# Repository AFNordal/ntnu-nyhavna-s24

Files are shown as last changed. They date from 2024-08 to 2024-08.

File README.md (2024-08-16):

 # My work at NTNU, summer '24
 ## Tracker box
Each tracker box contains a Marble Pico (RP2040 based development board), a BMI270 IMU and two F9P-ZED RTK compatible GNSS receivers with antennas. Everything is powered by a simple USB power bank. 

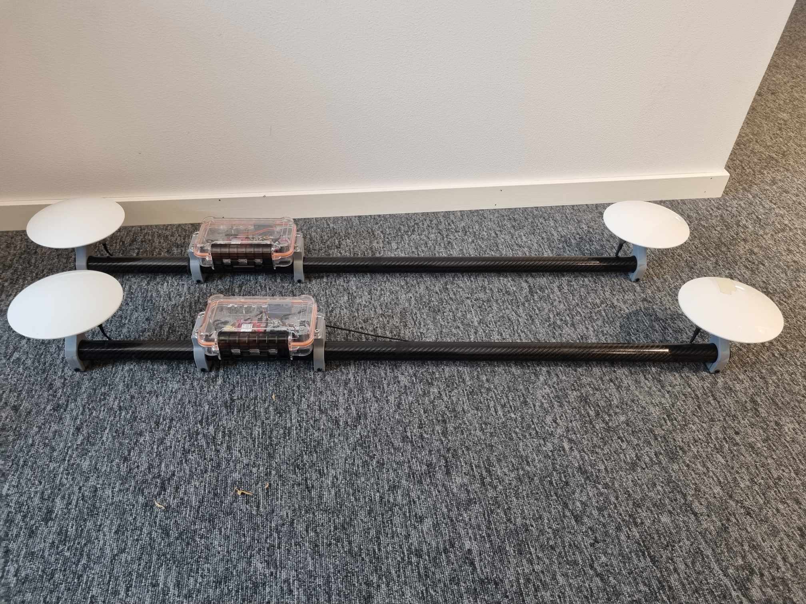
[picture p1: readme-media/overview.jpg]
Overview of tracker box assemblies


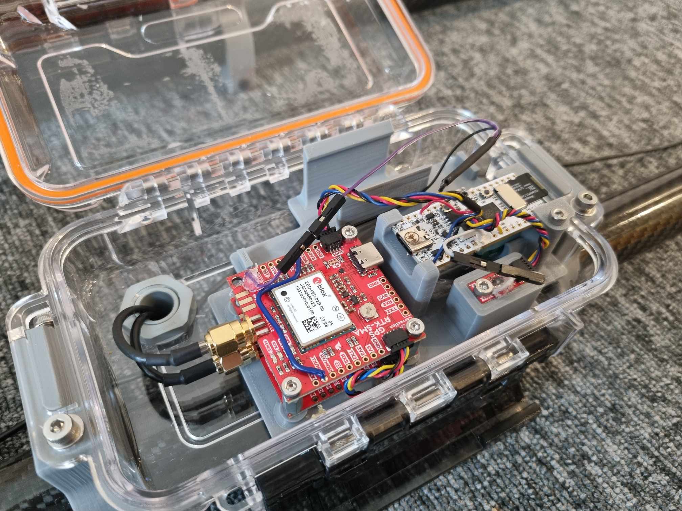
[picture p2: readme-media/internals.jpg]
Internals of tracker box


The boxes' purpose is to log accurately timed position and orientation data of maritime vessels.

 ### Usage
 1. Make sure the SD card is properly formatted, has enough free storage, and is inserted in the Pico. The card does not need to be emptied, and old files are not overwritten.
 2. Make sure that the three jumper cables and all I2C bus connectors are connected.
 3. Connect USB power to the Pico. After four seconds, the built-in LED on the pico should start blinking with two short blinks per second. If anything else happens, see [Troubleshooting](#Troubleshooting).
 4. Close the box and go track something.
 5. When you're done, simply unplug power. The onboard capacitor gives the Pico time to flush and close all files.
 6. The SD card now contains these files:
    - `IMU-[n].bin`
      - Contains raw IMU data in binary.
    - `F9P0-[n].bin` and `F9P1-[n].bin`
      - Contains raw F9P messages in binary.
    - `.count`
      - Contains the number `n` used in the file names of the newest data files. This is automatically incremented or created.

 #### Troubleshooting
When everything is working normally, the built-in LED on the Pico should blink with two short blinks each second.

If there is only one short blink each second, then core 1 of the Pico has become unresponsive. This has not occurred with the latest firmware version. Try resetting, power cycling, or re-flashing.

If the LED blinks quickly with 50% duty cycle, there has been a fatal error. Currently, this can be caused by:

 - Fatal error during SD card file system initialization
 - Unsuccessful IMU initialization
 - Fatal internal IMU error after initialization

Make sure that the SD card is properly inserted and that the I2C bus of the IMU is properly connected to the Pico, then reset or power cycle the Pico.

If the LED blinks quickly with ~16% duty cycle, the Pico has detected a brown-out and has flushed and closed all SD card writers to avoid corrupting the file system. A false detection has not yet occured. Resetting the Pico should restart the logging.

 ### Parsing

 #### Data format
The F9P data streams are copied directly to the data files.

The IMU data is stored as a stream of raw, little-endian structs. The struct is defined as
```
typedef struct
{
    bmi_data_t data;
    uint32_t sample_idx;
    uint8_t stamped;
    uint32_t _dummy0[3]; // To make the struct 32 bytes long
} IMU_sample_t;
```
where `bmi_data_t` is defined as
```
typedef struct
{
    int16_t ax;
    int16_t ay;
    int16_t az;
    int16_t gx;
    int16_t gy;
    int16_t gz;
} bmi_data_t;
```
This means that the data is structured as follows:

| byte # | field | type |
| ----- | --- | ---- |
| 0-1 | acc_x | int16 |
| 2-3 | acc_y | int16 |
| 4-5 | acc_z | int16 |
| 6-7 | acc_x | int16 |
| 8-9 | acc_y | int16 |
| 10-11 | acc_z | int16 |
| 12-15 | sample index | uint32 |
| 16 | acc_z | bool (uint8) |
| 17-31 | dummy | n.a. |

In python, this can be decoded with
```
struct.unpack("<" + "h"*6 + "I" + "B"*4 + "I"*3, raw_bytes)
```
which is applied in the next subsection.

 #### Parsing framework
The `parsing` directory contains a framework for parsing raw tracking data, synchronizing IMU data and F9P timestamps, plus some simple visualization tools. You can for instance replay the IMU data like seen below.

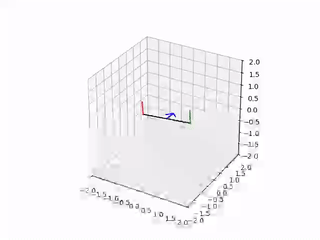
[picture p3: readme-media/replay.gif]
Animation of replayed IMU orientation


 ### Schematic
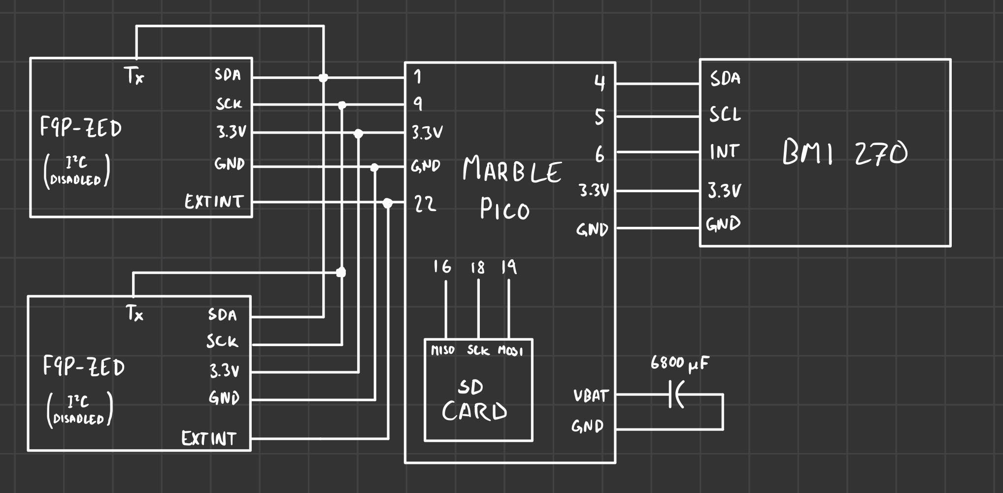
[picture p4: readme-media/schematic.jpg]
Schematic of Pico, F9Ps and IMU


 ### Firmware
The firmware uses both cores, `I2C0`, `UART0`, `UART1`, one alarm pool, four DMA channels and `DMA_IRQ_1`. The [SD card library](https://github.com/carlk3/no-OS-FatFS-SD-SDIO-SPI-RPi-Pico) uses two more DMA channels, `SPI0` and `DMA_IRQ_0`.

Core 0 handles initialization of the F9P interface, SD file system, and voltage monitoring. It is responsible for LED control, all SD operations, and voltage monitoring.

Core 1 handles initialization of the IMU and IMU interface, and is responsible for reading IMU data.

For accurate timestamping, the IMU data ready (DRDY) pulse is periodically forwarded to the F9Ps' EXTINT. This should happen around once every 2s. To be able to align IMU data and F9P timestamps that are offset by more than 2s, the interval between each pulse-forward is decreased by one IMU DRDY pulse for each pulse-forward. Every 64 pulse-forwards the interval is reset.

When a pulse is forwarded, the corresponding IMU sample's `stamped` field is set to 1. For all other samples it is set to 0.

The following two diagrams provide an overview of interactions with the IMU and F9Ps, respectively.

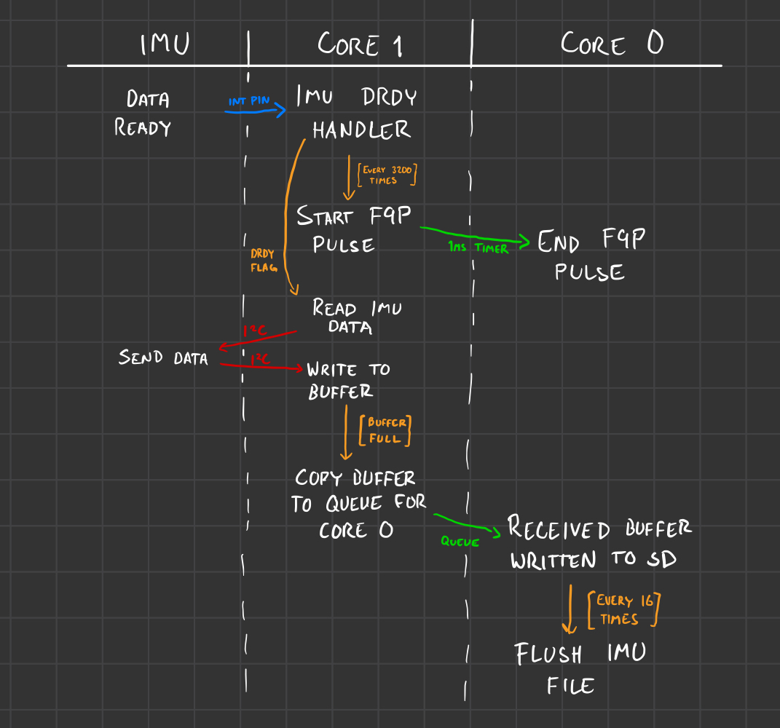
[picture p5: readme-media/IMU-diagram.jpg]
IMU diagram

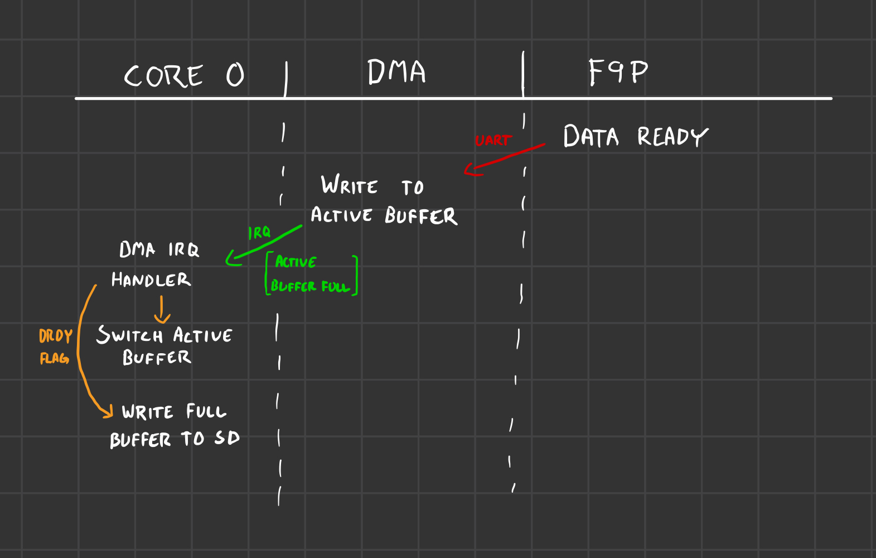
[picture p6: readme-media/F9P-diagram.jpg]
F9P diagram


 ## CAD work
I have also done some work in CAD to design the mounts and brackets for the tracking boxes, as well as some mounts for a different sensor rig. The `.f3z` archive files for all of these are also in this repository.

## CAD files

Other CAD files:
other cad/kamera-lidar-gnss v10.f3z
other cad/motor-bracket v7.f3d
tracking-box/CAD/ror-feste v8.f3d
tracking-box/CAD/tracker-box-2 v11.f3d

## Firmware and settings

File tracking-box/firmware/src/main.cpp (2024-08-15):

#include <stdio.h>

#include "pico/stdlib.h"
#include "pico/multicore.h"
#include "pico/util/queue.h"
#include "sys_utils.h"
#include "bmi270.h"
#include "sd_utils.h"
#include "battery.h"
#include "f9p.h"

// No. of 32 bytes long structs to be buffered before writing to sd
#define IMU_BUF_SIZE 1536
#define F9P_INTERRUPT_INTERVAL_S 2
#define F9P_INTERRUPT_PIN 22
#define F9P_RX0_PIN 1
#define F9P_RX1_PIN 9
#define BMI_DRDY_PIN 6
#define BMI_SDA_PIN 4
#define BMI_SCL_PIN 5

// Used to communicate to core 0 that core 1 is alive
queue_t heartbeat_queue;

// Whether main power is disconnected
volatile bool pwr_disconnected = false;
// Whether IMU has new data
volatile bool IMU_drdy = false;
// Whether the IMU is ready to take real readings
volatile bool IMU_armed = false;
// Whether the most recent IMU sample coincides with a pulse to the F9P's
volatile bool IMU_sample_stamped = false;
volatile uint32_t IMU_sample_idx = 0;
queue_t IMU_queue;

typedef struct
{
    bmi_data_t data;
    uint32_t sample_idx;
    uint8_t stamped;
    uint32_t _dummy0[3]; // To make the struct 32 bytes long
} IMU_sample_t;

void core1_entry(void);

// callback for when IMU has new data ready
void IMU_drdy_handler(uint gpio, uint32_t event_mask)
{
    static uint8_t stamp_offset = 32;
    static uint32_t prev_stamped = 0;
    if (IMU_armed && (IMU_sample_idx - prev_stamped == stamp_offset + BMI_ODR_HZ * F9P_INTERRUPT_INTERVAL_S))
    {
        prev_stamped = IMU_sample_idx;
        IMU_sample_stamped = true;
        f9p_send_interrupt();
        if (stamp_offset-- == 0)
            stamp_offset = 64;
    }
    else
    {
        IMU_sample_stamped = false;
    }
    IMU_drdy = true;
}

// Checks vbus voltage
void adc_handler(uint16_t level)
{
    if (level < 1600)
        pwr_disconnected = true;
}

int main()
{
    stdio_init_all();
    set_sys_clock_133mhz();
    led_init();
    busy_wait_cycles_ms(4000);

    queue_init(&heartbeat_queue, sizeof(uint8_t), 1);

    FATFS fs;
    sd_mount(&fs);

    // Read 'count' from .count file; Increment count and use
    // result in file names to avoid overwriting.
    FIL count_file;
    sd_open(&count_file, ".count", FA_WRITE | FA_READ | FA_OPEN_ALWAYS);
    char count_buf[32];
    uint32_t count;
    if (sd_readnum(&count_file, &count) != PICO_OK)
        count = 0;
    else
        count++;
    sd_rewind(&count_file);
    sd_writenum(&count_file, count);
    sd_close(&count_file);

    // Create IMU file
    FIL IMUfile;
    char filename[32];
    sprintf(filename, "IMU-%d.bin", count);
    sd_open(&IMUfile, filename, FA_CREATE_ALWAYS | FA_WRITE);

    // Create F9P files
    FIL F9Pfile0, F9Pfile1;
    char filename0[32], filename1[32];
    sprintf(filename0, "F9P0-%d.bin", count);
    sprintf(filename1, "F9P1-%d.bin", count);
    sd_open(&F9Pfile0, filename0, FA_CREATE_ALWAYS | FA_WRITE);
    sd_open(&F9Pfile1, filename1, FA_CREATE_ALWAYS | FA_WRITE);

    INFO("SD file system initialized\n");

    alarm_pool_t *core0_alarms = alarm_pool_get_default();
    // Poll capacitor voltage every 5ms
    battery_init(5, adc_handler, core0_alarms);
    INFO("Battery management initialized\n");

    // Timer used to pulse interrupt pin
    f9p_init(F9P_RX0_PIN, F9P_RX1_PIN, F9P_INTERRUPT_PIN, core0_alarms);
    INFO("F9P's initialized\n");

    queue_init(&IMU_queue, sizeof(IMU_sample_t) * IMU_BUF_SIZE, 1);
    multicore_launch_core1(core1_entry);
    INFO("Launched core 1\n");

    uint16_t write_count = 0;
    IMU_sample_t *IMUbuffer = new IMU_sample_t[IMU_BUF_SIZE];
    uint8_t *F9Pbuffer = new uint8_t[F9P_BUF_SIZE];
    while (!pwr_disconnected)
    {
        heartbeat_blink(&heartbeat_queue);

        uint32_t datarate;
        if (f9p_chan0_drdy(&F9Pbuffer))
        {
            sd_write(&F9Pfile0, F9Pbuffer, F9P_BUF_SIZE);
            sd_sync(&F9Pfile0);
            INFO("Wrote F9P0 file\n");
        }
        if (f9p_chan1_drdy(&F9Pbuffer))
        {
            sd_write(&F9Pfile1, F9Pbuffer, F9P_BUF_SIZE);
            sd_sync(&F9Pfile1);
            INFO("Wrote F9P1 file\n");
        }

        if (!queue_try_remove(&IMU_queue, IMUbuffer))
            continue;
        sd_write(&IMUfile, IMUbuffer, sizeof(IMU_sample_t) * IMU_BUF_SIZE);
        // INFO("Wrote IMU file\n");
        if ((++write_count) % 16 == 0)
        {
            sd_sync(&IMUfile);
            INFO("Flushed IMU file\n");
        }
    }
    sd_close(&IMUfile);
    sd_close(&F9Pfile0);
    sd_close(&F9Pfile1);
    sd_unmount();
    INFO("SD card unmounted\n");

    info_blink();
    for (;;)
        ;
}

void core1_entry(void)
{
    // Dummy variable
    uint8_t heartbeat_const = 1;

    bmi_init(BMI_SDA_PIN, BMI_SCL_PIN);
    bmi_set_drdy_pin(BMI_DRDY_PIN, IMU_drdy_handler);
    INFO("BMI270 initialized\n");

    IMU_sample_t *IMUbuffer = new IMU_sample_t[IMU_BUF_SIZE];

    // Flush first readings
    for (uint16_t i = 0; i < 128; i++)
    {
        while (!IMU_drdy)
            ;
        IMU_drdy = false;
        bmi_read_FIFO(nullptr, bmi_get_FIFO_length());
    }
    IMU_armed = true;
    while (true)
    {
        queue_try_add(&heartbeat_queue, &heartbeat_const);

        if (!IMU_drdy)
            // No data ready
            continue;
        IMU_drdy = false;
        bmi_data_t IMUdata;
        if (bmi_read_sensors(&IMUdata) == 1)
        {
            // False drdy; This happens some times
            INFO("False drdy\n");
            continue;
        }
        IMUbuffer[IMU_sample_idx % IMU_BUF_SIZE] = (IMU_sample_t){IMUdata,
                                                                  IMU_sample_idx,
                                                                  IMU_sample_stamped};
        IMU_sample_idx++;
        if (IMU_sample_idx % IMU_BUF_SIZE == 0)
        {
            if (!queue_try_add(&IMU_queue, IMUbuffer))
                ERROR("Queue full\n");
        }
    }
}

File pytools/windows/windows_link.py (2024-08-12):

from pathlib import Path
import asyncio
import time
import serial
from websockets.legacy.server import Serve, WebSocketServerProtocol
from wtools import get_url
import serial.tools.list_ports
import win32api


def load_script(script: bytes):
    driveD = Path("D:\\")
    driveE = Path("E:\\")
    for idx in range(20):

        print(f"Looking for pico dir {idx}")

        if driveD.exists():
            info = win32api.GetVolumeInformation(str(driveD))
            # print(info)
            assert info[0] == "RPI-RP2"
            print("Trying to flash")
            with driveD.joinpath("flash.uf2").open("wb") as f:
                f.write(script)
            print("Wrote script")
            return
        elif driveE.exists():
            info = win32api.GetVolumeInformation(str(driveE))
            # print(info)
            assert info[0] == "RPI-RP2"
            print("Trying to flash")
            with driveE.joinpath("flash.uf2").open("wb") as f:
                f.write(script)
            print("Wrote script")
            return
        try:
            serial.serial_for_url(url=get_url(), baudrate=1200, timeout=0.2)
        except Exception as e:
            print("Failed to set magic baudrate,", e)
            pass
        time.sleep(0.5)

    raise Exception("Could not flash")


async def forward(websocket: WebSocketServerProtocol):
    loop = asyncio.get_running_loop()
    for _ in range(20):
        print("Attempting to open COM port")
        try:
            ser = serial.serial_for_url(url=get_url(), baudrate=9000, timeout=0.1)
            break
        except Exception as e:
            time.sleep(0.2)
    else:
        raise Exception("Connection error")

    async def reader():
        while websocket.open:
            if data := await loop.run_in_executor(None, ser.read, 4096):
                await websocket.send(data)

    async def writer():
        while websocket.open:
            if data := await websocket.recv():
                await loop.run_in_executor(None, ser.write, data)

    # async def watchdog():
    #     while websocket.open:
    #         await asyncio.sleep(0.5)
    #         ser.write(b"\xff\x01\xff\xff")

    await asyncio.gather(reader(), writer())
    ser.close()


async def handle(websocket: WebSocketServerProtocol):
    if websocket.path == "/flash":
        print("Received flash request")
        data = await websocket.recv()
        load_script(data)
        await websocket.send(b"OK")

    elif websocket.path == "/forward":
        while True:
            print("Starting terminal")
            await forward(websocket)

    else:
        raise Exception("Unknown path")


async def main():
    print("Starting server")
    async with Serve(handle, "0.0.0.0", 8765, ping_timeout=None):
        await asyncio.Future()


if __name__ == "__main__":
    asyncio.run(main())

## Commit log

2024-06-13 working sensor data
2024-06-17 SD and IMU working
2024-06-20 debugging DMA
2024-08-05 parsing and visualizing IMU data. Parsing f9p time
2024-08-07 New file structure in parsing. GNSS time synced to IMU. Bugfix in tracker firmware.
    [bmi270.cpp, main.cpp]
2024-08-12 fixed off-by-1 in timestamp intervals
    [main.cpp]
2024-08-12 added fusion360 archives
    [ror-feste v6.f3d, tracker-box-2 v11.f3d]
2024-08-15 updated tracker-box cad, and added other cad
    [kamera-lidar-gnss v10.f3z, motor-bracket v7.f3d, ror-feste v6.f3d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]
2024-08-16 IMU data format in readme
